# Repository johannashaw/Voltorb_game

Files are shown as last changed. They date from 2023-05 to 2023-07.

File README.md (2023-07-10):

# Voltorb_game
## A recreation of the Voltorb minigame from Pokemon Soul-Silver in the form of an embedded device that I designed and programmed.

I have chosen to affectionately rename the game Boom-Boom since "Voltorm minigame from Pokemon Soul-Silver" was a mouthful.

- The PCB was designed to incorperates a 5x5 button matrix and have the game displayed on an OLED using I2C interfacing. 

- The Software component was designed to be used with the ATmega328P-P microchip and the SSD1306 OLED.

- SSD1306, I2C, and sci libraries were all provided to me by my NAIT instructor, Simon Walker.

## Game description:
The game is displayed on the OLED as a "game board" of 25 tiles, arranged in a 5x5 grid.
Each tile on the grid begins each level blank and will contain a value of either a 1, 2, 3, or a bomb.
To the right of each row and below each column there will be: 
  - A line containing between 0 and 5 "ticks", indicating the amount of bombs in that row/column
  - A second line below that, there will be a 2-digit leading-zero number, indicating the sum total of the point tiles (1s, 2s, and 3s) in the given row/column

### Gameplay: 
The objective of the game is to reveal all of the tiles containing a 2 or a 3 in each round, while avoiding revealing any the bomb tiles. 
  - The player starts the game at level 1. 
  - Each round begins with all tiles hidden and the player has 1 point.
  - The player's Level-Points will be multiplied by the value of each point tile the player reveals.
  - If all of the 2's and 3's in a given round have been revealed, they: 
	* Have won the round. 
	* Move up a level.

  - If the player reveals a bomb, they: 
	* Have lost the round. 
	* Have their Level-Points fall down to 0.   
	* Drop down a level.
 
  - At the end of each round, the player's Level-Points will be added to their Total-Points and the board resets for the next round.  
  - The levels start at 1 and go up to 9, increasing in difficulty as the palyer moves up in levels.

### User Interface
The user is able to interact with the game through the 5x5 button matrix. Pressing a given button will select the corresponding tile in the game.
Once a tile is selected:
  - If a round is in progress, then it will reveal the tile underneath.
  - If the round is over and only one tile has been revealed, it will reveal all the remaining tiles.
  - If the round is over and all the remaining tiles have been revealed, it will start a new round.
  
E.g.: (Game with the tiles revealed)
```
        Boom-Boom
        Level: 2
        Total-Points: 127
        Level-Points: 36
        ______________________________________________
        |        |        |        |        |        | '
        |    1   |    2   |  Bomb  |    1   |    1   |  05
        |________|________|________|________|________|        
        |        |        |        |        |        | 
        |    1   |    1   |    1   |    2   |    1   |  06
        |________|________|________|________|________|
        |        |        |        |        |        | ''
        |  Bomb  |    1   |  Bomb  |    1   |    1   |  03
        |________|________|________|________|________|
        |        |        |        |        |        | ''
        |    1   |    3   |  Bomb  |    1   |  Bomb  |  05
        |________|________|________|________|________|
        |        |        |        |        |        | '
        |    1   |    1   |    1   |  Bomb  |    3   |  06
        |________|________|________|________|________|
          '                '''      '        '
             04       08       02       05       06
```

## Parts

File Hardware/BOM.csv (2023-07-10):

Date: | 3/24/2023 14:14
Component Count: | 48
Ref | Qnty | Value | Cmp name | Footprint | Description | Vendor
C1, C2, | 2 | 1uF | 1206 Capacitor | Capacitor_SMD:C_1206_3216Metric_Pad1.33x1.80mm_HandSolder | Unpolarized ceramic capacitor
C3, C4, | 2 | 18pF | 1206 Capacitor | Capacitor_SMD:C_1206_3216Metric_Pad1.33x1.80mm_HandSolder | Unpolarized ceramic capacitor
C5, C6, | 2 | 0.1uF | 1206 Capacitor | Capacitor_SMD:C_1206_3216Metric_Pad1.33x1.80mm_HandSolder | Unpolarized ceramic capacitor
D1, | 1 |  | 1206 Orange LED | LED_SMD:LED_1206_3216Metric_Pad1.42x1.75mm_HandSolder | Light emitting diode
J2, | 1 |  | TerminalBlock_bornier-2_P5.08mm | TerminalBlock:TerminalBlock_bornier-2_P5.08mm | 2 Position 5.08 mm Fixed Terminal Blocks
J1, J3, J4, J5 | 19 |  | 2.54mm Vertical PinHeader |  | 2.54mm Vertical PinHeader
R1, | 1 | 330 Ohms | R_US | Resistor_SMD:R_1206_3216Metric_Pad1.30x1.75mm_HandSolder | Resistor, US symbol
R2, R3, R4, R5, R6, | 5 | 10 kOhms | R_US | Resistor_SMD:R_1206_3216Metric_Pad1.30x1.75mm_HandSolder | Resistor, US symbol
SW1, | 1 | Power | SPST N.O. toggle DIP -- 108-0047-EVX | Special_Switch:108-0047-EVX_SPST | Single Pole Single Throw (SPST) switch
SW2, | 1 | RESET | SPST N.O. push SMD -- PTS645 | Button_Switch_SMD:SW_SPST_PTS645 | Push button switch, generic, two pins
SW3 -> SW27 | 25 | SPST | SPST N.O. push DIP -- B3F-1000 | Special_Switch:B3F-1000 | Push button switch, generic, two pins
U1, | 1 | ATmega328P-P | ATmega328P-P | Package_DIP:DIP-28_W7.62mm | 20MHz, 32kB Flash, 2kB SRAM, 1kB EEPROM, DIP-28
U2, | 1 | 3.3 Vout | MCP1754S-3302xMB | Package_TO_SOT_SMD:SOT-89-3 | Fixed 150mA Low Dropout Voltage Regulator, Positive, 3.3V output, SOT-89
Y1, | 1 | 16MHz SMD_HC49-SD | Crystal | Crystal:Crystal_SMD_HC49-SD_HandSoldering | Two pin crystal
 | 4 | 4-40 Standoff | 91780A164 | #4-40 X 0.5 INCH ALUMINUM F-F STANDOFF
 | 4 | 4-40 Screw | 90272A106 | #4-40 X 0.25 INCH NC MACHINE SCREW

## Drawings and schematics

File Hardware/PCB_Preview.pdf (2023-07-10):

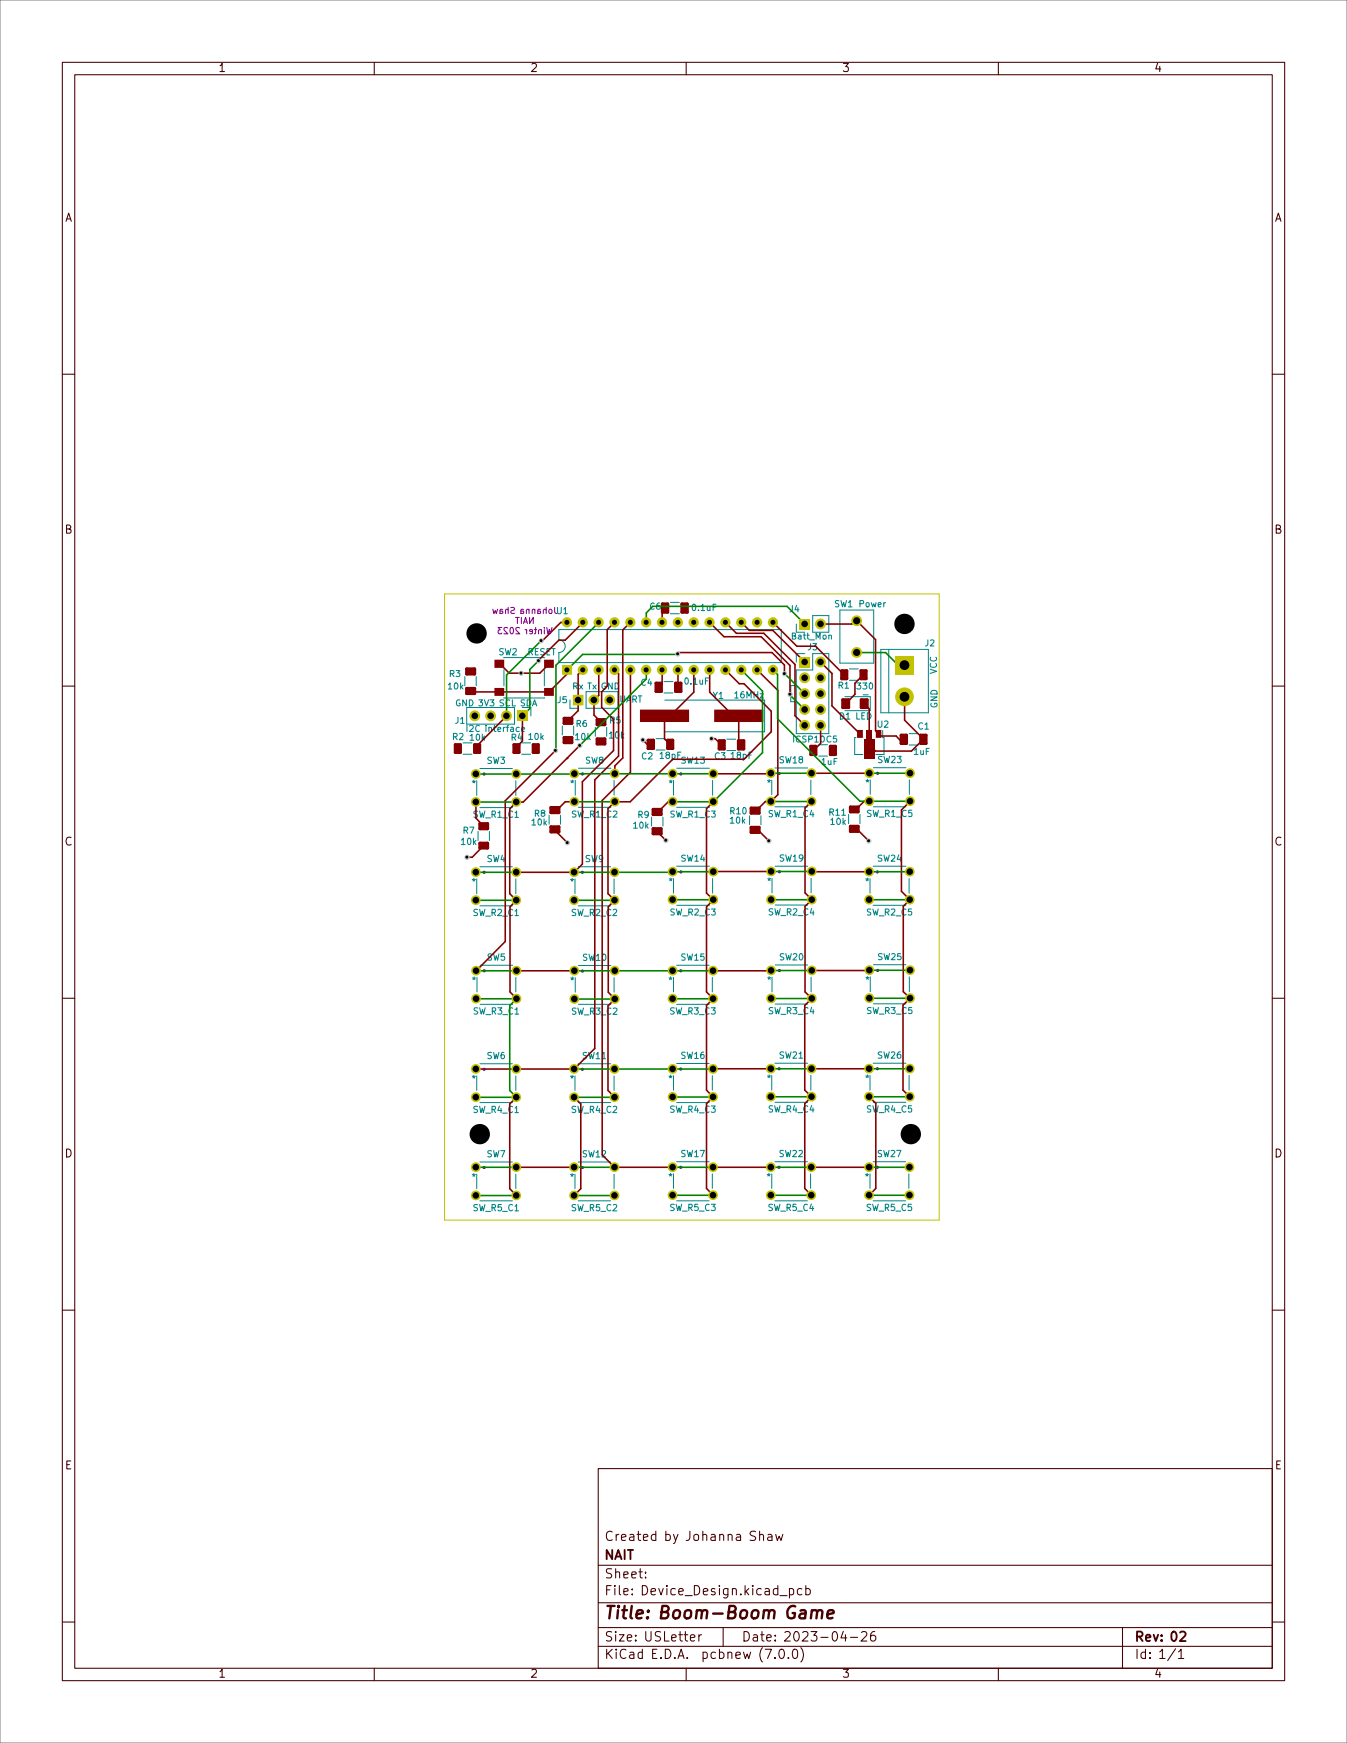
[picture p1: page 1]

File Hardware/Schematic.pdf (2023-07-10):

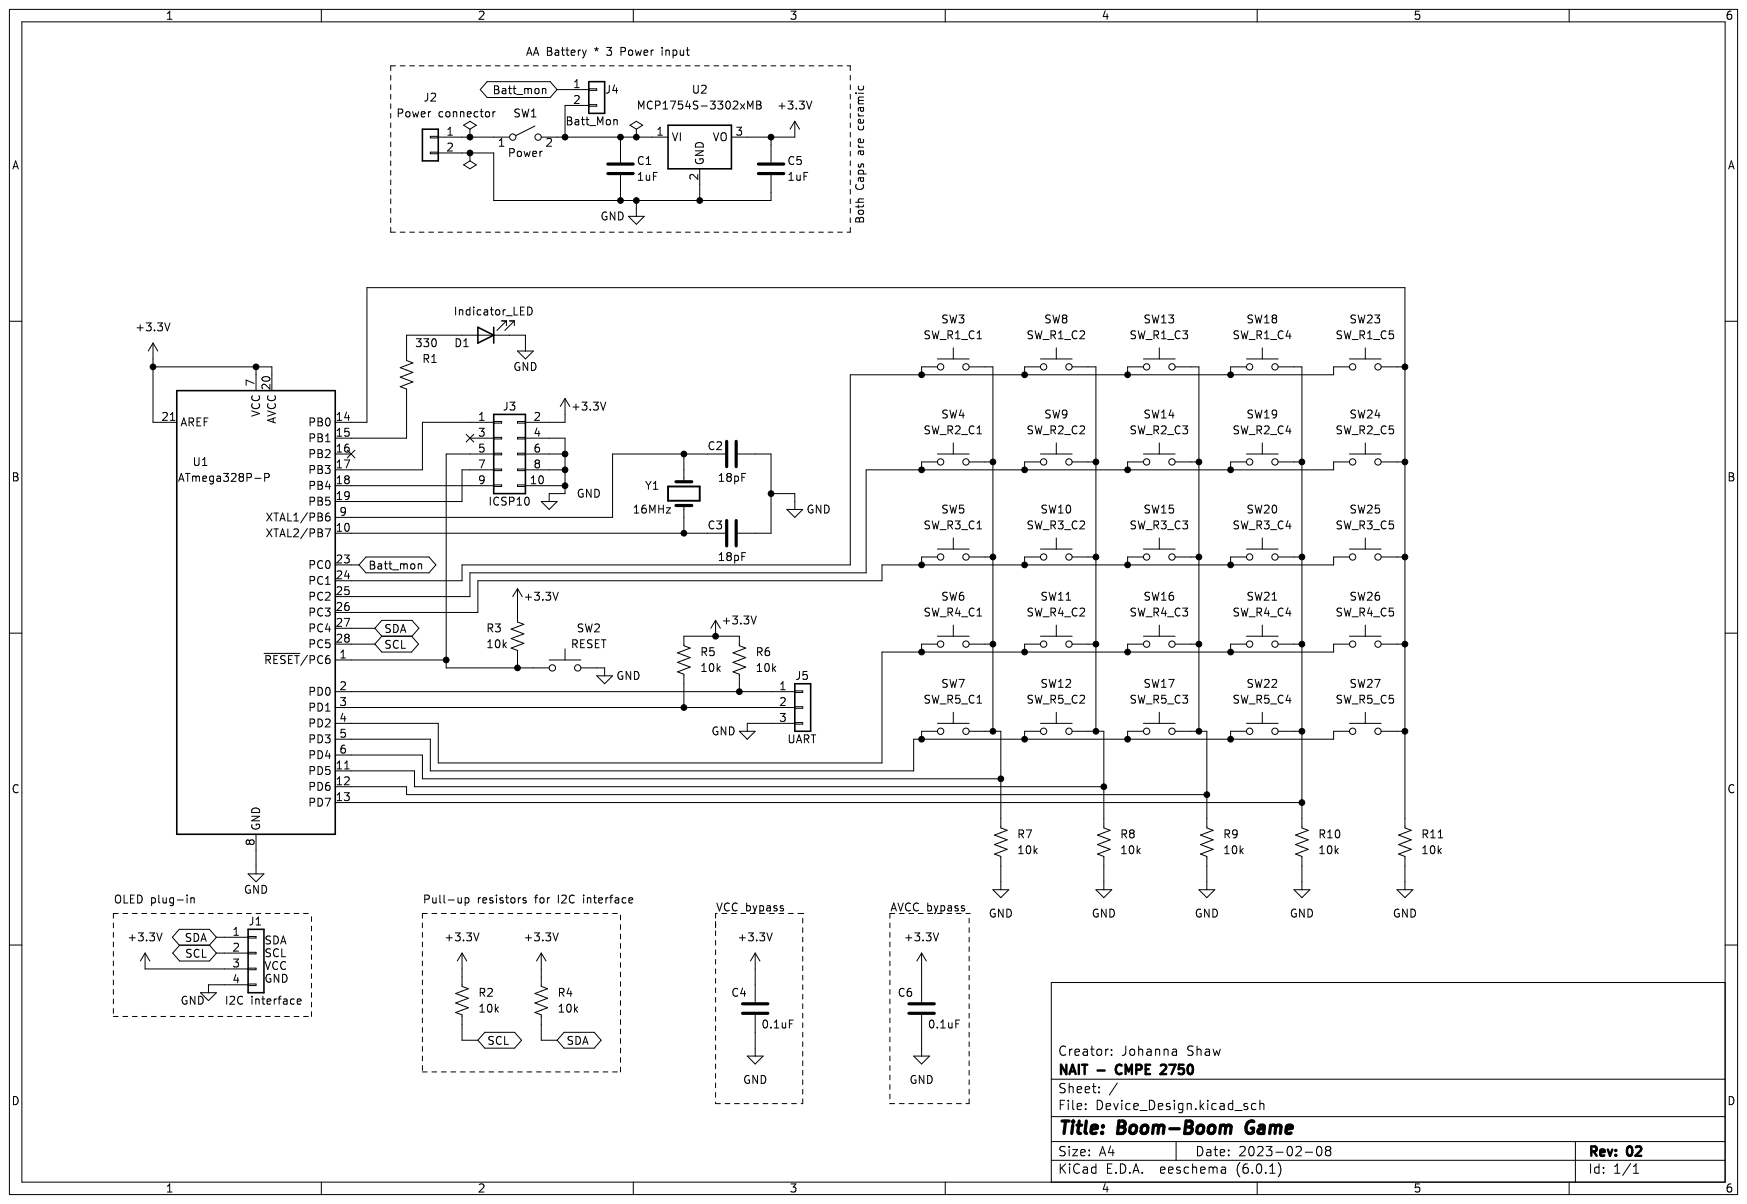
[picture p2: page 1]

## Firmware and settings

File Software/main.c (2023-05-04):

/*
 * Game_v3.c
 *
 * Created: 3/31/2023 1:38:12 PM
 * Author : Johanna Shaw
 * Description :	The main file for the Voltorb game. Will handle button callbacks, and OLED displays for things that
					are game specific and require multiple GamePlay pointers.
 */ 
#ifndef F_CPU
#define F_CPU 2E6 // with external xtal enabled, and clock div/8, bus == 2MHz
#endif


#include <avr/io.h>
#include <util/delay.h> // have to add, has delay implementation (requires F_CPU to be defined)
#include <stdio.h>
#include "sci.h"
#include "Buttons.h"
#include "SSD1306.h"
#include "Gameplay.h"
#include "GameUI.h"

// Macros
#ifndef IndicatorLed_B
#define IndicatorLed_B 0b00000010		// #define IndicatorLed PORTB1
#endif

// Macros to be uncommented when testing and debugging respectively.

//#ifndef TESTING
//#define TESTING
//#endif
//
//#ifndef DEBUG_MAIN
//#define DEBUG_MAIN
//#endif


// for accessing the board
#define Board(row, col) (board[row * 5 + col])



//****************************************************************************
//								Global Variables:
//****************************************************************************

// Pointers to the variables used in gameplay
char *board; 
int *totalPoints;
int *Level;
int *LevelPoints;

// holds which row the LevelPoints should be drawn too,
// so that I don't have to change this in a bunch of places later if I decide to move stuff around
char pointRow = -1;

//****************************************************************************
//								Function Declarations:
//****************************************************************************

void ButtonPressed(int row, int col);
void ButtonHeld(int row, int col);

void StartGame();
void TestGame();

// OLED UI functions
void RevealAllTiles();
void FullNewScreen();


int main(void)
{
	//  **************************************************************
	//							local variables
	//  **************************************************************
	
	
	//  **************************************************************
	//							One-Time Inits:
	//  **************************************************************
	
	// set up serial for 2MHz bus, 9600 BAUD, no interrupts
	SCI0_Init(F_CPU, 9600, 0);
	SCI0_TxString("\n\nHello from the ATmega328P!\n\n");
	
	// initialize OLED
	SSD1306_DispInit();
	
	// initialize the Game UI
	//GameInitUI();

	board = GetArray_pt();
	totalPoints = GetTotalPoints_pt();
	Level =GetLevel_pt();
	LevelPoints = GetLevelPoints_pt();

	// initialize the game.
	Boardinit();
	
	#ifdef TESTING
	TestGame();
	
	// initialize the buttons and set buttonPressed and held callback functions
	ButtonsSetup(&ButtonPressed, &ButtonHeld);
	#endif
	
	#ifndef TESTING
	// display the title screen on the OLED
	GameInitUI();
	
	// initialize the buttons and set buttonPressed and button_held callback functions
	// StartGame will get called when a button is first pressed, (this gets reassigned after title screen is displayed)
	// ButtonHeld will be called when a button is pressed for 2 seconds
	ButtonsSetup(&StartGame, &ButtonHeld);
	
	#endif
	
		
	// main program loop - don't exit
	while(1)
	{
		// current version is running based on delays, may change to interrupts later.
		_delay_ms(100);
				
		// toggle the led, inicating game is running
		PINB = IndicatorLed_B;
		
		// Does checks of each the 25 game buttons. Will pass the row and column to 
		// the respective callback funtions if a button is pressed or held for 2 seconds
		CheckButtons();
	}
}



//****************************************************************************
//								Function Declarations:
//****************************************************************************


// A button was pressed, do something with that information.
void ButtonPressed(int row, int col)
{
	char output[30];
	
	// tells the GamePlay file that the user has pressed a button
	// this is the only way in which the user will interact with the game itself, and apart from making a newLevel at the 
	char retval = TryReveal(row, col);
	
	
	#ifdef DEBUG_MAIN
	sprintf(output, "row = %d, col = %d\n", row, col);
	SCI0_TxString(output);
	
	
	qPrint("retval = %d\n\n", retval);
	#endif

	
	
	// if 0, no changes so return
	if (retval == 0)
		return;
		
	// only one of the tiles has changed:
	if (retval < 3)
	{
		ChangeTile(row, col, Board(row,col) & ValueBits, (Board(row,col) & RevealedBit) >> 3);
	
		// update level points
		sprintf(output, "%9d", *LevelPoints);
		SSD1306_StringXY(0, pointRow, output);
		
		// indicate the lose state
		if (retval == 2 && *LevelPoints == 0)	
			SSD1306_StringXY(0, 7, "You Lost.");
		// indicate the win state
		else if (retval == 2 && *LevelPoints > 0)
			SSD1306_StringXY(0, 7, "Win!     ");
			
			
		SSD1306_Render();
		return;
	}
	// End of a level, show the board:
	if (retval == 3)
	{
		RevealAllTiles();
		SSD1306_Render();
		return;
	}
	
	// retval == 4, time to clear and reset the screen for a new level.
	FullNewScreen();
}

// A button was pressed, do something with that information.
void ButtonHeld(int row, int col)
{
	#ifdef DEBUG_MAIN
	char output[18];
	sprintf(output, "held %d %d", row, col);
	
	
	SSD1306_StringXY(0,1,output);
	Indicator_Tog;
	#endif
	
	#ifdef TESTING
	RevealAllTiles();
	
	#endif
}


#ifdef DEBUG_MAIN
void CheckChange()
{
	char output[50];
	//SCI0_TxString("CheckChanged:\n");
	for (int i = 0; i < 25; i++)
	{
		// Access via pointers:
		//sprintf(output, "Tile *(board + %d) = %d\n", (int)i, (int)*(board + i)); 
		//SCI0_TxString(output);
		
		// Access like an array:
		sprintf(output, "Tile %d = %d\n", (int)i, board[i]); 
		SCI0_TxString(output);
	}


	sprintf(output, "\ntp = %d, lvl = %d, lvlpts = %d\n\n", *totalPoints, *Level, *LevelPoints);
	SCI0_TxString(output);

}
#endif


void RevealAllTiles()
{
	for (int i = 0; i < 25; i++) 
	{
		ChangeTile(i / 5, i % 5, board[i] & ValueBits, 1);
	}
	SSD1306_Render();
}

void FullNewScreen()
{
	char output[50];
	int row = 0;
	
	
	#ifdef DEBUG_MAIN
	CheckChange();
	#endif
	
	SSD1306_Clear();

	//display the game title
	SSD1306_StringXY(0, row++, "Boom-Boom");
	row++;
	
	//display level
	sprintf(output, "Level: %2d", *Level);
	SSD1306_StringXY(0, row++, output);

	//display total points
	SSD1306_StringXY(0, row++, "Total:");
	sprintf(output, "%9d", *totalPoints);
	SSD1306_StringXY(0, row++, output);

	//display level points
	SSD1306_StringXY(0, row++, "Points:");
	pointRow = row;		// so that the Points will always be printed to the right row
	sprintf(output, "%9d", *LevelPoints);
	SSD1306_StringXY(0, row++, output);



	row++;
	
	// make game grid
	MakeGrid();


	// display the bombs and points for each row/column'
	for (int i = 0; i < 5; i++)
	{
		char rowBombs = 0, colBombs = 0, rowPts = 0, colPts = 0;
		for (int j = 0; j < 5; j++)
		{
			// going through i row: Board(i, j)
			rowBombs += (Board(i, j) & ValueBits) == 0;
			rowPts += Board(i, j) & ValueBits;
			
			// going through i column: Board(j, i)
			colBombs += (Board(j, i) & ValueBits) == 0;
			colPts += Board(j, i) & ValueBits;
		}
		// set for row
		DisplayBombLine(rowBombs, i, 5);
		DisplayPointSum(rowPts, i, 5);
		// set for col
		DisplayBombLine(colBombs, 5, i);
		DisplayPointSum(colPts, 5, i);
	}
	
	SSD1306_Render();
}

// Only called at the beginning of the game (when not in Test mode)
// 
void StartGame()
{
	//NewLevel();

	// display the new level on the OLED
	FullNewScreen();
	
	// Reassign the button-press callback so that it actually plays the game.
	ReassignButtonCallback(&ButtonPressed);
}


// Code used in testing.
void TestGame()
{
	char output[50];
	
	SCI0_TxString("\nBoard in main.TestGame:\n");
	
	// Display each of the tiles
	
	
	//StartGame();
	FullNewScreen();
		
	SCI0_TxString("\nBack to Board in main.TestGame:\n");
	
}

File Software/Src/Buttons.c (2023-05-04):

/*
 * Buttons.c
 *
 * Created:	2023-04-12 10:23:34 PM
 * Author:	Johanna Shaw
 */ 
 

#include <avr/io.h>
#include <stdio.h>
#include "sci.h"
#include "Buttons.h"
#include "SSD1306.h"

// Set Rows 1, 2, and/or 3 to high
#define ROW1to3_C_On(Row) PORTC |= Row
// Set Rows 1, 2, and/or 3 to low
#define ROW1to3_C_Off(Row) PORTC &= ~(Row)

// Set Rows 4 and/or 5 to high
#define ROW4to5_D_On(Row) PORTD |= Row
// Set Rows 4 and/or 5 to low
#define ROW4to5_D_Off(Row) PORTD &= ~(Row)

	// for outputs, set to a 1							// for inputs set to a 0
	// Rows: (Outputs)									// Columns: (Inputs)
	// 1 = PortC1											// 1 = PortD4
	// 2 = PortC2											// 2 = PortD5
	// 3 = PortC3											// 3 = PortD6
	// 4 = PortD2											// 4 = PortD7
	// 5 = PortD3											// 5 = PortB0


//****************************************************************************
//						Globals (private to this file):
//****************************************************************************

// Each int in ArePressed corresponds to a button. Holds the count indicating how long its been pressed for.
int ArePressed[25];	
			
// A flag indicating whether or not there was a button pressed last time the buttons were checked.
// Used so that resetting ArePressed array to 0 doesn't happen more than the one time is needed.
char WasPressed = 0;		 

// Function that gets called when a button is initially pressed
void (*ButtonpressedCallback)(int, int);		
void (*ButtonHeldCallback)(int, int);		





//****************************************************************************
//									Functions:
//****************************************************************************


// setting up the buttons that are being used
// Also sets up the indicator LED
void ButtonsSetup(void (*PushedCallback)(int, int), void (*HeldCallback)(int, int))
{
	// set global Callback function pointer to the one passed to us
	ButtonpressedCallback = *PushedCallback;
	ButtonHeldCallback = *HeldCallback;
	
	// Set the rows as as outputs
	DDRC |=	ROW1_C | ROW2_C | ROW3_C;
	DDRD |= ROW4_D | ROW5_D;
	
	// set the row outputs to high
	ROW1to3_C_On(ROW1_C | ROW2_C | ROW3_C);
	ROW4to5_D_On(ROW4_D | ROW5_D);
	
	//disable the pull-ups *IMPORTANT*
	PORTD &= ~(COL1_D | COL2_D | COL3_D | COL4_D);
	PORTB &= ~COL5_B;
	
	// Set column pins as inputs
	DDRD &= ~(COL1_D | COL2_D | COL3_D | COL4_D);		//0b 0000 1111
	DDRB &= ~COL5_B;									//0b 1111 1110	
	
		
	// indicator led setup
	DDRB |= IndicatorLed_B;
	
	
	// set all bits in ArePressed to 0
	for (int i = 0; i < 25; i++)
		ArePressed[i] = 0;	
}

// Used in the Check BUttons function
// checks to see if any of the buttons in the given row is pushed, if so, invokes the callback function 
void __checkColsHelper(int row)
{
	// Adjusting the row value because it was initially designed to start from 1 (but I quickly regretted that decision)
	row--;
	
	//for columns 1 through 4, pins on port D
	for (int col = 0; col < 4; col++)
	{
		if(PIND & (1 << (col + 4)))
		{
			ArePressed[row*5 + col]++;
			
			// Callback for when the button is first pressed
			if (ArePressed[row*5 + col] == 1)
				ButtonpressedCallback(row, col);
				
			// Callback for when the button is held for 2 seconds
			else if (ArePressed[row*5 + col] == 10)
			{
				ButtonHeldCallback(row, col);
			}
		}
		else
		{
			ArePressed[row*5 + col] = 0;
		}
	}
	
	//for col 5, pin on port B
	if (PINB & COL5_B)
	{
		ArePressed[row*5 + 4]++;	
		
		// Callback for when the button is first pressed
		if (ArePressed[row*5 + 4] == 1)
			ButtonpressedCallback(row, 4);
			
		// Callback for when the button is held for 2 seconds
		else if (ArePressed[row*5 + 4] == 10)
			ButtonHeldCallback(row, 4);
	}
	// The button was released, set button's pressed-Count to 0
	else
		ArePressed[row*5 + 4] = 0;
}


// Does a check for if any of the buttons have been pressed.
void CheckButtons()
{
	// if no buttons are pressed, leave
	if (!((PIND & (COL1_D | COL2_D | COL3_D | COL4_D)) | (COL5_B & PINB)))
	{
		// set WasPressed flag to false
		WasPressed = 0;
		return;
	}
	
	// no buttons were pressed in the previous check, you can now reset the ArePressed array.
	if (!WasPressed)
	{
		for (int i = 0; i < 25; i++)
			ArePressed[i] = 0;
	}
		
	// set the outputs of the rows to 0
	ROW1to3_C_Off(ROW1_C | ROW2_C | ROW3_C);
	ROW4to5_D_Off(ROW4_D | ROW5_D);
	
	// go through each row, setting the output to 1, and seeing if any of the columns inputs are high
	// for rows 1 to 3, the pins on port C
	for (int row = 1; row <= 3; row++ )
	{
		//set the row we're checking to high
		ROW1to3_C_On(1 << row);
		
		//check each column
		__checkColsHelper(row);
		
		// set the row back to low
		ROW1to3_C_Off(1 << row);
	}
	// for rows 4 and 5, the pins on port D
	for (int row = 4; row <= 5; row++ )
	{
		ROW4to5_D_On(1 << (row - 2));
		
		//check each column
		__checkColsHelper(row);
		
		// We're no longer checking that row, set it back to low
		ROW4to5_D_Off(1 << (row - 2));
	}
	
	// set all rows back to high
	ROW1to3_C_On(ROW1_C | ROW2_C | ROW3_C);
	ROW4to5_D_On(ROW4_D | ROW5_D);
	
	
	WasPressed = 1;
}


// if you want the button to do something different midway through the application
void ReassignButtonCallback(void (*CallbackFunc)(int, int))
{
	// set global Callback function pointer to the one passed to us
	ButtonpressedCallback = *CallbackFunc;
}

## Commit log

2023-05-04 Trying to fix ^M in github display
    [Buttons.c, Buttons.h]
2023-07-10 Added hardware design files
    [BOM.csv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]
